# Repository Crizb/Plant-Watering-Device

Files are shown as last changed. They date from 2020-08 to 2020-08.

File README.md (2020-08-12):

# Plant Watering Device with HTML server Capabilities

Another simple device which was made to test capabilities of NodeMCU ESP8266, and displaying informations on HTML Server through WI-Fi.

So to start simply. I wanted to monitor the condition of plants in my house and to make myself sure that they won't die if I forget to water them everyday.
I used some soil Humidity sensors to measure the ground and water level sensors to measure how much water is left in the water bottle which was supplying water to the pumps. 

This project was not meant to be professional. It was just a test of NodeMcu ESP8266 and it's capabilities to create a remote Wi-Fi monitor.

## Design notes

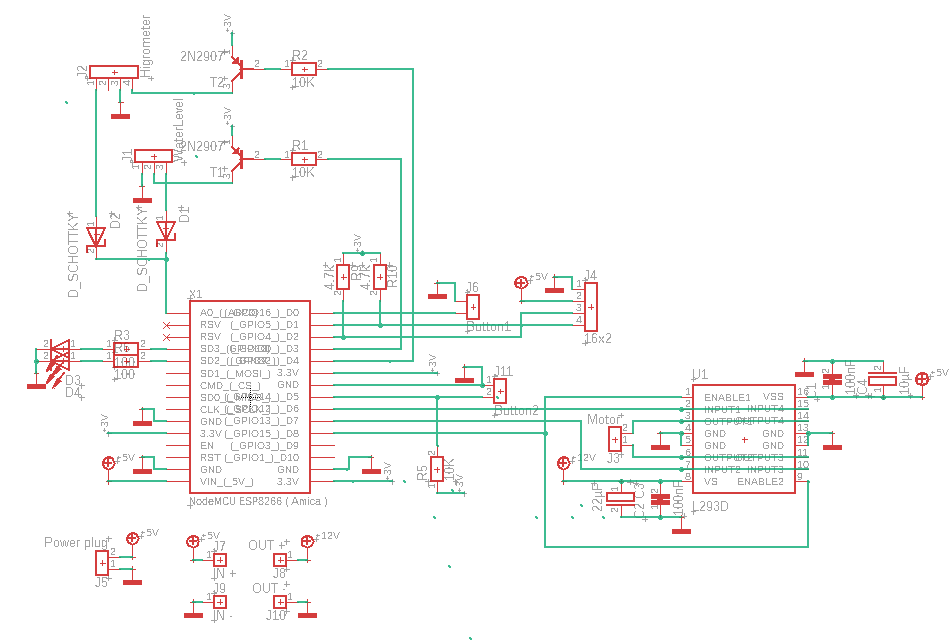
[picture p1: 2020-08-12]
JPGs/PlantWateringSolution - Schematic.png

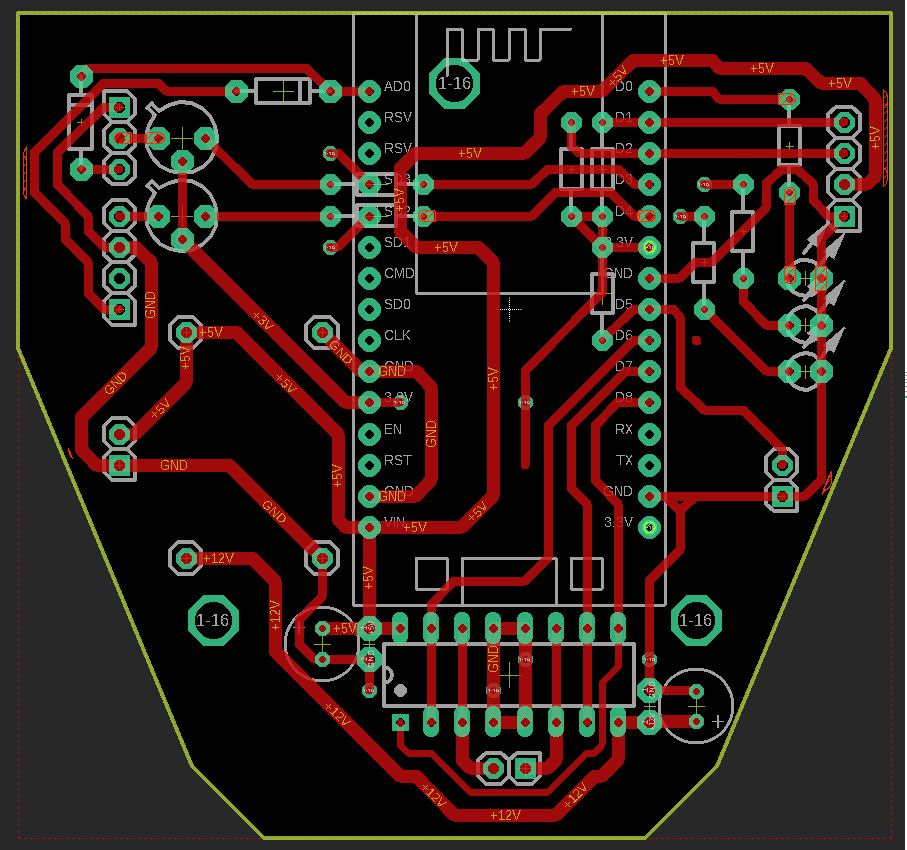
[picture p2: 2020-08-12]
JPGs/PlantWateringSolution - PCB.png

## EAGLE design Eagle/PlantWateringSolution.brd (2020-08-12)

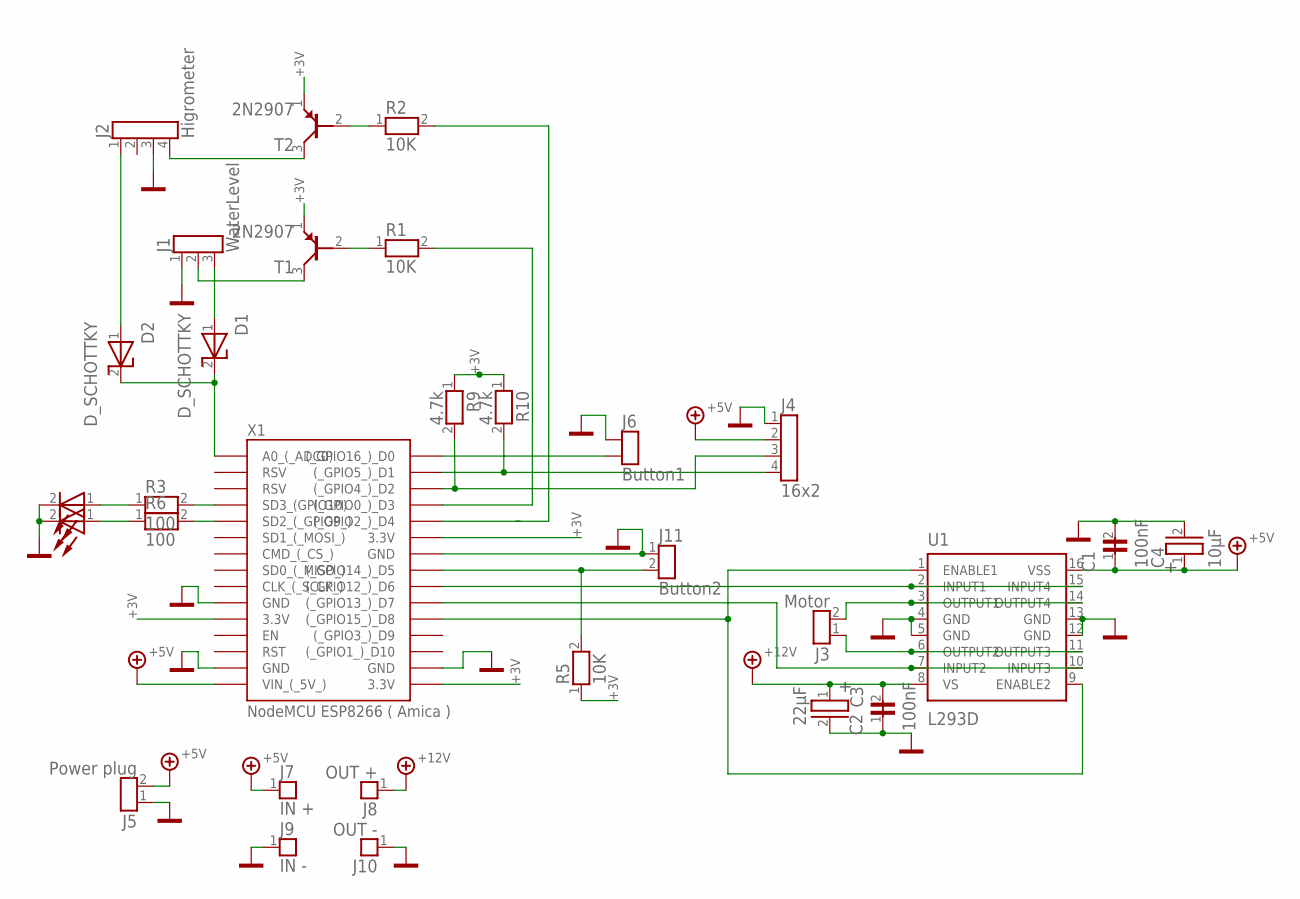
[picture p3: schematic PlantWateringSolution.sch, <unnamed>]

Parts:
C1: 100nF; 6X6R2,54_DISC_18
C2: 100nF; 6X6R2,54_DISC_19
C3: 22µF; D6R2,54_ELKO_20
C4: 10µF; D6R2,54_ELKO_21
D1: D_SCHOTTKY; DO35_5
D2: D_SCHOTTKY; DO35_6
D3: HLMA-KH00; LED_3MM_RED_47
D4: HLMA-KH00; LED_3MM_RED_42
J1: WaterLevel; STIFTLEISTE_1X03_G_2,54_2
J2: Higrometer; STIFTLEISTE_1X04_G_2,54_3
J3: Motor; STIFTLEISTE_1X02_G_2,54_4
J4: 16x2; STIFTLEISTE_1X04_G_2,54_43
J5: Power plug; STIFTLEISTE_1X02_G_2,54_50
J7: IN +; STIFTLEISTE_1X01_G_2,54_32
J8: OUT +; STIFTLEISTE_1X01_G_2,54_33
J9: IN -; STIFTLEISTE_1X01_G_2,54_34
J10: OUT -; STIFTLEISTE_1X01_G_2,54_35
J11: Button2; STIFTLEISTE_1X02_G_2,54_53
R1: 10K; 0204_MET_9
R2: 10K; 0204_MET_10
R3: 100; 0204_MET_46
R5: 10K; 0204_MET_31
R6: 100; 0204_MET_41
R9: 4.7k; 0204_MET_55
R10: 4.7k; 0204_MET_56
T1: 2N2907; TO18_7
T2: 2N2907; TO18_8
U1: L293D; DIL16_1
X1: NodeMCU ESP8266 ( Amica ); NODEMCU_ESP8266_DEV_0

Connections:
1: R2.1, T2.2 (B)
(_GPIO16_)_D0: X1.30 ((_GPIO16_)_D0)
+3V: R5.1, R9.1, R10.1, T1.1 (E), T2.1 (E), X1.11 (3.3V), X1.16 (3.3V), X1.25 (3.3V)
+5V: C1.1, C4.1 (+), J4.2, J5.2, J7.1, U1.16 (VSS), X1.15 (VIN_(_5V_))
+12V: C2.2, C3.1 (+), J8.1, U1.8 (VS)
A: D3.1 (A), R3.1
B: R1.1, T1.2 (B)
BUTTON3: J11.2, R5.2, X1.23 ((_GPIO14_)_D5)
ENABLE: U1.1 (ENABLE1), U1.9 (ENABLE2), X1.20 ((_GPIO15_)_D8)
GND: C1.2, C2.1, C3.2 (-), C4.2 (-), D3.2 (K), D4.2 (K), J1.1, J2.3, J4.1, J5.1, J9.1, J10.1, J11.1, U1.4 (GND), U1.5 (GND), U1.12 (GND), U1.13 (GND), X1.10 (GND), X1.14 (GND), X1.17 (GND), X1.24 (GND)
HIGROMETER_SIG: D2.1 (A), J2.1
HIGROMETER_VIN: J2.4, T2.3 (C)
INPUT1: U1.2 (INPUT1), U1.15 (INPUT4), X1.22 ((_GPIO12_)_D6)
INPUT2: U1.7 (INPUT2), U1.10 (INPUT3), X1.21 ((_GPIO13_)_D7)
K: D1.2 (K), D2.2 (K), X1.1 (A0_(_ADC0))
OUTPUT1: J3.2, U1.3 (OUTPUT1), U1.14 (OUTPUT4)
OUTPUT2: J3.1, U1.6 (OUTPUT2), U1.11 (OUTPUT3)
SCL: J4.4, R10.2, X1.29 ((_GPIO5_)_D1)
SD2_(_GPIO9_): R6.2, X1.5 (SD2_(_GPIO9_))
SDA: J4.3, R9.2, X1.28 ((_GPIO4_)_D2)
SIG$127: D4.1 (A), R6.1
SIG$131: R3.2, X1.4 (SD3_(GPIO10))
SIG$151: J1.2, T1.3 (C)
SIG$155: R2.2, X1.26 ((_GPIO2_)_D4)
WATERLEVEL_PNP: R1.2, X1.27 ((_GPIO0_)_D3)
WATERLEVEL_SIG: D1.1 (A), J1.3

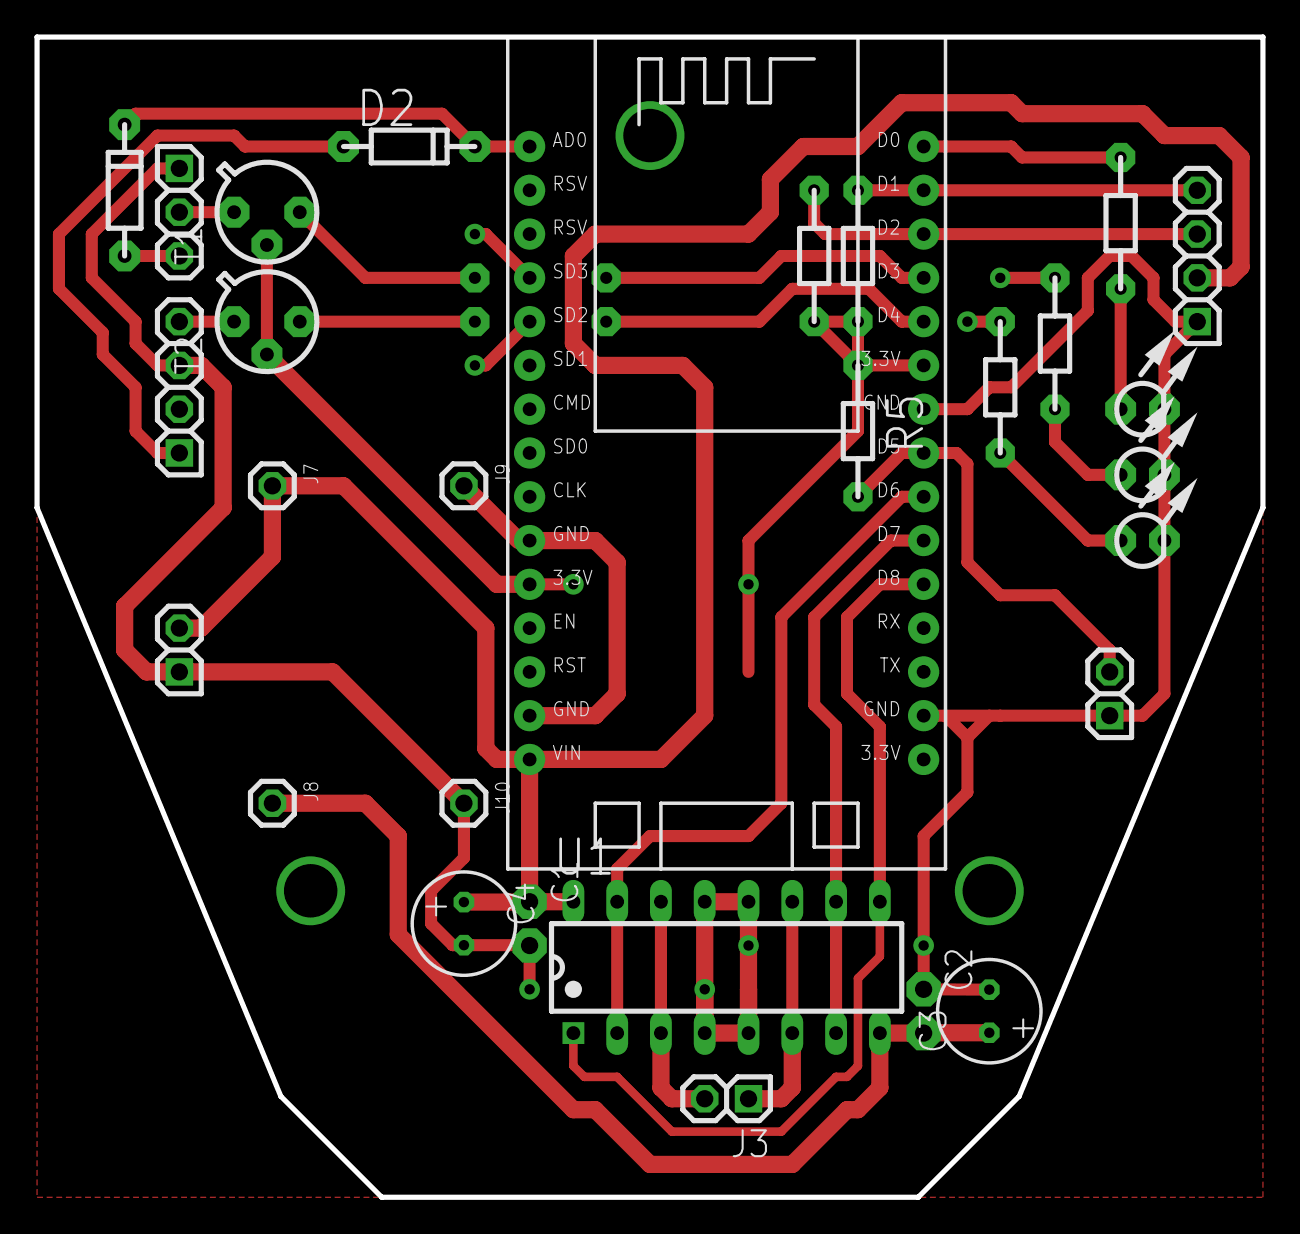
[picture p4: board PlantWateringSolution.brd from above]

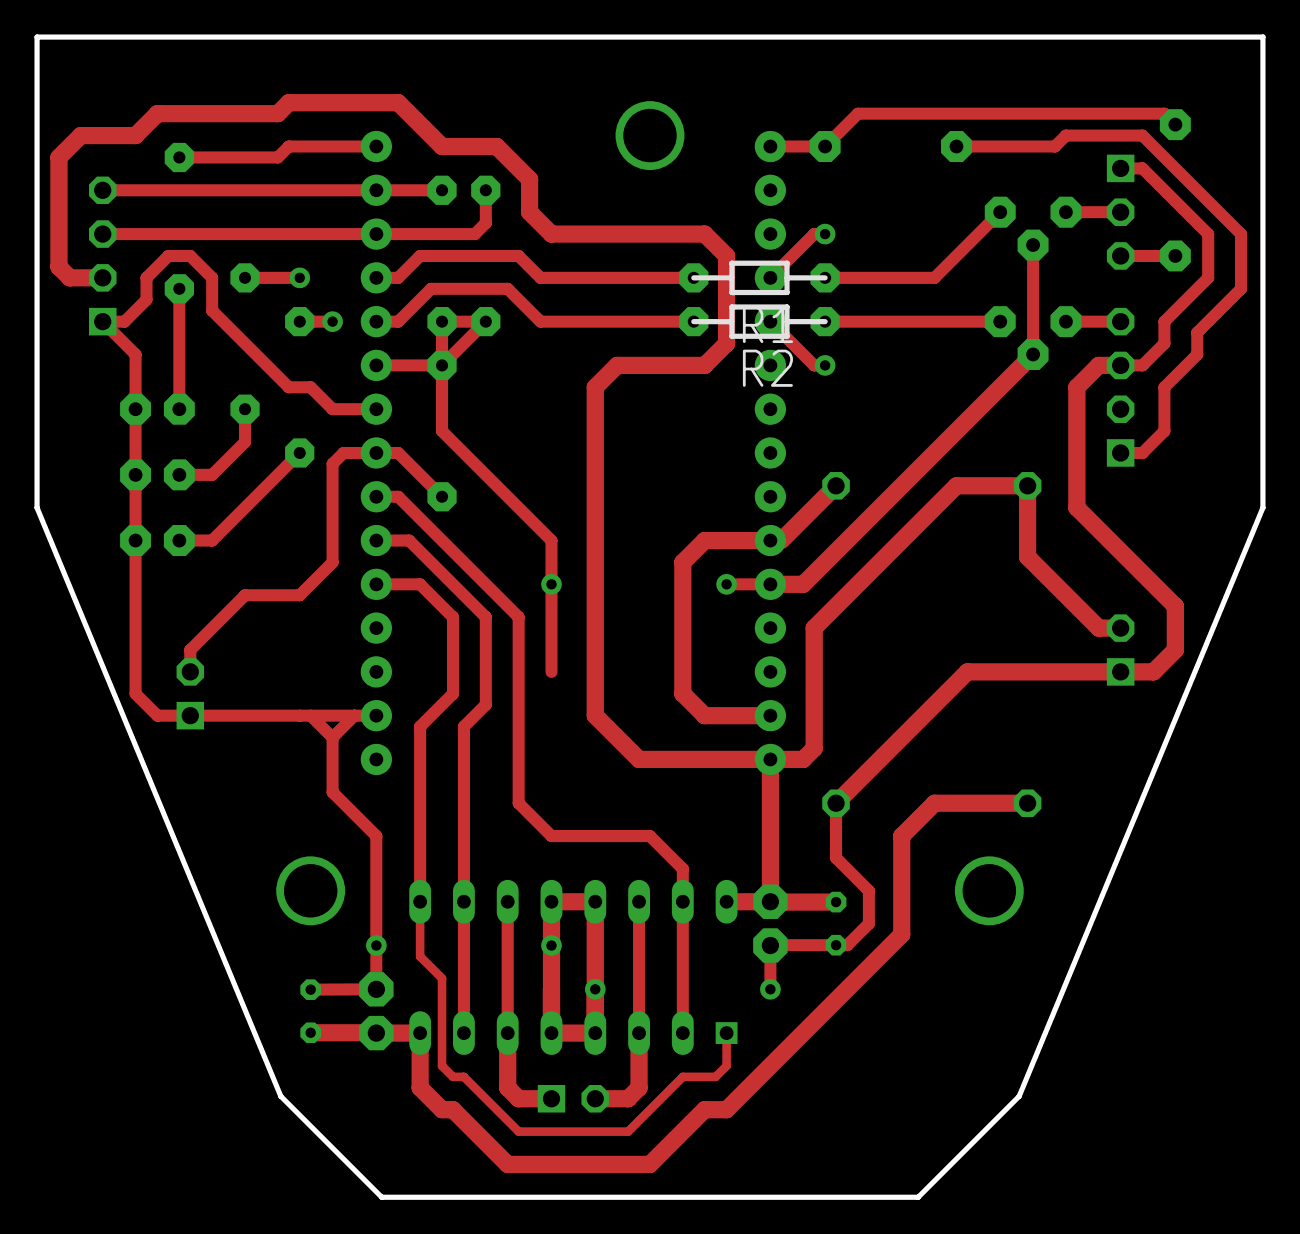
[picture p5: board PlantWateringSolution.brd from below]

Board: 2 copper layers, 71.1 x 67.3 mm, 31 parts (2 on the bottom side), 25 nets.

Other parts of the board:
D5: HLMA-KH00; LED_3MM_RED_49
R4: 100; 0204_MET_48

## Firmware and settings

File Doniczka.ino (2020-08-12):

#include <Wire.h>
#include <LiquidCrystal_I2C.h>
#include <ESP8266WiFi.h>
#include <ESP8266WebServer.h>
#include <WiFiUdp.h>
#include <NTPClient.h>

const char* ssid = "putYourSSIDHere";
const char* haslo = "putYourPasswordHere";

int minimalHumidityTreshold = 60;

#define button1 14
#define button2 16
#define analogIn A0
#define waterSensor 0
#define humiditySensor 2
#define pumping 12
#define sucking 13
#define motor 15

LiquidCrystal_I2C lcd(0x27,16,2);


const long timezone = 3600 * 2;
int dst = 0;

int wateringDuration = 5 * 1000;
int hour1 = 6;
int hour2 = 21;

char dayOfTheWeek[7][15] = {"Niedziela", "Poniedzialek", "Wtorek", "Sroda", "Czwartek", "Piatek", "Sobota"};

WiFiUDP ntpUDP;
NTPClient timeClient(ntpUDP, "europe.pool.ntp.org", timezone);
ESP8266WebServer server(80);

int hour = 0;
int minute = 0;
int second = 0;
  
int sensorID = 0;
int waterLevel = 0;
int soilHumidity = 0;
int wasPlantWatered = 0;
int button1Pressed = 0;
int button2Pressed = 0;
int button2Released = 0;
unsigned long timeStartingLoop = 0;
unsigned long timeWatering = 0;


void setup() {
  pinMode(button2, INPUT);
  pinMode(analogIn, INPUT);
  pinMode(button1, INPUT);
  pinMode(waterSensor, OUTPUT);
  pinMode(humiditySensor, OUTPUT);
  pinMode(pumping, OUTPUT);
  pinMode(sucking, OUTPUT);
  pinMode(motor, OUTPUT);
  
  Serial.begin(115200);
  Wire.begin(4, 5);
  lcd.begin(16, 2);
  lcd.backlight();
  
  WiFi.begin(ssid, haslo);
  lcd.print("Laczenie z WiFi");
  lcd.setCursor(0, 1);
  int i = 0;
  while (WiFi.status() != WL_CONNECTED){
    delay(1000);
    lcd.print("*");
    i++;
    if (i > 16){
      lcd.clear();
      lcd.print("Brak WiFi");
      lcd.setCursor(0, 1);
      lcd.print("Sprawdz siec");
    }
  }
  lcd.clear();
  lcd.print("WiFi Polaczone");
  timeClient.begin();
  delay(500);
  lcd.clear();
  
  server.on("/", handle_OnConnect);
  server.onNotFound(handle_NotFound);
  server.begin();
  
  Serial.println("Twoje IP: ");  Serial.println(WiFi.localIP());
  lcd.print("Twoje IP: ");  
  lcd.setCursor(0, 1);
  lcd.print(WiFi.localIP());
  delay(5000);
  lcd.clear();
  //kontrolaCzujnikow();
}

void kontrolaCzujnikow(){
  if((millis() - timeStartingLoop >= 50) && (sensorID == 0)){
    digitalWrite(waterSensor, LOW);
    digitalWrite(humiditySensor, HIGH);
    if (millis() - timeStartingLoop >= 1000){
      lcd.setCursor(0, 0); lcd.print("Poziom Wody:     ");
      int wartoscCzujnika = analogRead(analogIn);
      waterLevel = map(wartoscCzujnika, 200, 500, 0, 100);
      if (waterLevel < 0) {waterLevel = 0;}
      if (waterLevel > 100) {waterLevel = 100;}
      lcd.setCursor(12, 0); lcd.print(waterLevel);
      lcd.print("%");
      timeStartingLoop = millis(); sensorID = 1;
      second ++;
    }
  }
  if((millis() - timeStartingLoop >= 50) && (sensorID == 1)){
    digitalWrite(waterSensor, HIGH);
    digitalWrite(humiditySensor, LOW);
    if (millis() - timeStartingLoop >= 1000){
      lcd.setCursor(0, 0); lcd.print("Wilgotnosc:     ");
      int wartoscCzujnika = analogRead(analogIn);
      soilHumidity = map(wartoscCzujnika, 0, 1023, 100, 0);
      lcd.setCursor(12, 0); lcd.print(soilHumidity);
      lcd.print("%");
      timeStartingLoop = millis(); sensorID = 0;
      second ++;
    }
  }
}

void podlewanie(){
  if (timeWatering == 0){
    digitalWrite(pumping, HIGH);
    digitalWrite(sucking, LOW);
    digitalWrite(motor, HIGH);
    timeWatering = millis();
  }
  if(millis() - timeWatering >= wateringDuration){
    digitalWrite(pumping, LOW);
    digitalWrite(sucking, LOW);
    digitalWrite(motor, LOW);
    timeWatering = 0;
    wasPlantWatered = 1;
    button1Pressed = 0;
  }
}

void ustawianieCzasu(){
  timeClient.update();
  hour = timeClient.getHours();
  minute = timeClient.getMinutes();
  second = timeClient.getSeconds(); 
}

void loop() { 
  if (button2Released == 1){
    lcd.clear();
    lcd.noBacklight();
    digitalWrite(pumping, LOW);
    digitalWrite(sucking, LOW);
    digitalWrite(motor, LOW);
    digitalWrite(waterSensor, HIGH);
    digitalWrite(humiditySensor, HIGH);
    if ((digitalRead(button2) == 0) || (button2Pressed == 1)){
      button2Pressed = 1;
      if (digitalRead(button2) == 1){button2Released = 0; button2Pressed = 0;}
    }
  }
  if (button2Released == 0){
    lcd.backlight();
    while(WiFi.status() != WL_CONNECTED){
      lcd.setCursor(0, 0);
      lcd.print("Ponowne laczenie");
      delay(1000);
      lcd.clear();
      delay(1000);
    }
    for(int i = 0; i <= 20000; i++){
      server.handleClient();
    }
    kontrolaCzujnikow();
    ustawianieCzasu();
    lcd.setCursor(0, 1);
    if (waterLevel > 0){
      lcd.print(hour); lcd.print(":");
      lcd.print(minute); lcd.print(":");
      lcd.print(second); lcd.print("            ");
      if ((digitalRead(button1) == 0) || (button1Pressed == 1)){
        button1Pressed = 1;
        if(digitalRead(button1) == 1){
          podlewanie();
        }
      }
      if ((hour == hour1) || (hour == hour2)){
        if ((wasPlantWatered == 0) && (soilHumidity <= minimalHumidityTreshold)){
          podlewanie();
        }
      }
    }
    if (waterLevel == 0){
      lcd.print("Uzupelnij wode! ");
      digitalWrite(pumping, LOW);
      digitalWrite(sucking, LOW);
      digitalWrite(motor, LOW);
    }
    if ((hour != hour1) && (hour != hour2)){
        wasPlantWatered = 0;
    }
    if ((digitalRead(button2) == 0) || (button2Pressed == 1)){
      button2Pressed = 1;
    if (digitalRead(button2) == 1){button2Released = 1; button2Pressed = 0;}
    }
  }
}

void handle_OnConnect() {
  server.send(200, "text/html", SendHTML()); 
  Serial.println("Server OK");
}

void handle_NotFound(){
  server.send(404, "text/plain", "Not found");
  Serial.println("Server NOT OK");
}

String SendHTML(){
  String ptr = "<!DOCTYPE html> <html>\n";
  ptr +="<head><meta http-equiv=\"refresh\" content=\"2\", name=\"viewport\" content=\"width=device-width, initial-scale=1.0, user-scalable=no\">\n";
  ptr +="<title>Monitoring doniczki</title>\n";
  ptr +="<style>html { font-family: Helvetica; display: inline-block; margin: 0px auto; text-align: center;}\n";
  ptr +="body{margin-top: 50px;} h1 {color: #444444;margin: 50px auto 30px;}\n";
  ptr +="p {font-size: 24px;color: #444444;margin-bottom: 10px;}\n";
  ptr +="</style>\n";
  ptr +="</head>\n";
  ptr +="<body>\n";
  ptr +="<div id=\"webpage\">\n";
  ptr +="<h1>Monitoring doniczki</h1>\n";

  if(waterLevel > 0){
    ptr +="<p>Poziom Wody: ";
    ptr +=(int)waterLevel;
    ptr +="%</p>";
  }
  else{
    ptr +="<p>Poziom Wody: ";
    ptr +="BRAK, Uzupelnij wode";
  }
  ptr +="<p>Wilgotnosc Gleby: ";
  ptr +=(int)soilHumidity;
  ptr +="%</p>";
  
  ptr +="</div>\n";
  ptr +="</body>\n";
  ptr +="</html>\n";
  return ptr;
}

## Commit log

2020-08-12 Eagle Board and Schematic File
    [PlantWateringSolution.brd, PlantWateringSolution.sch]
2020-08-12 Pictures of Schematic and Board to preview
2020-08-12 Simple testing Arduino Code
